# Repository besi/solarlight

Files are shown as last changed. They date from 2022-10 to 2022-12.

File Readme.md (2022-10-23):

# Solar Light
A smart, solar powered light that lights up in various colors.

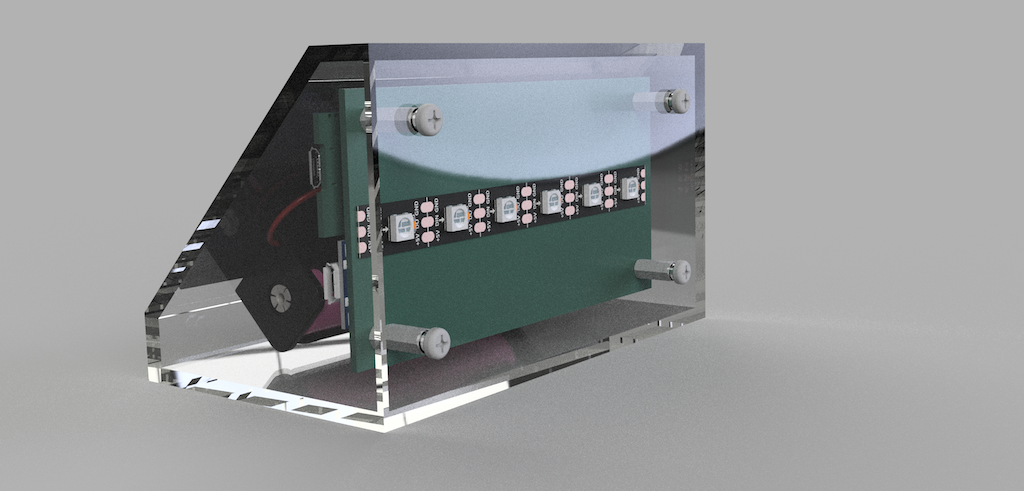
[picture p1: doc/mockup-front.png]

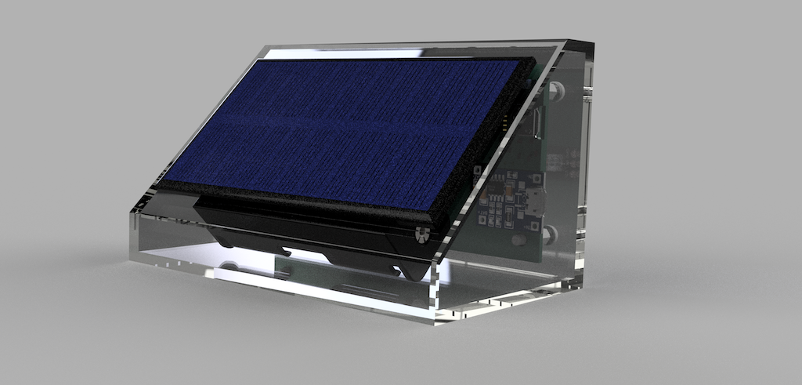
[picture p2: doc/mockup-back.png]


# Parts
The following parts are used in the project.

| Identifier  | Description | 
| --- | --- |
| [Microcontroller][]  | Wemos D1 Mini |
| [Battery][] | 18650 Lipo Battery with holder |
| [Charger][] | TP4056 Lipo Charger  |
| [Solar Panel][] | 110x60mm Solar Panel  |
| [Voltage Regulator][] | MCP1700-3302E  |
| [Neopixels][] | Neopixel WS2812b  |
| LED | Status LED  |
| Resistor | Resistor for LED Value? |
| Capacitor | Value? |

[Neopixels]: https://www.bastelgarage.ch/5m-ws2812b-60led-m-led-neopixel-strip-rolle
[Solar Panel]: https://www.bastelgarage.ch/solarzelle-5v-200ma-1w-110x60mm?search=solar%20panel
[Charger]: https://www.bastelgarage.ch/tp4056-lithium-lipo-akku-batterie-lademodul-micro-usb-5v-1a
[Battery]: https://www.bastelgarage.ch/li-ion-akku-3000ma-18650-mit-schutzelektronik-und-stecker?search=schutzelektronik
[Microcontroller]: https://www.reichelt.de/de/de/d1-mini-esp8266-v2-0-d1-mini-p253978.html?r=1
[Voltage Regulator]:https://www.digikey.ch/de/products/detail/microchip-technology/MCP1700-3302E-TO/652680

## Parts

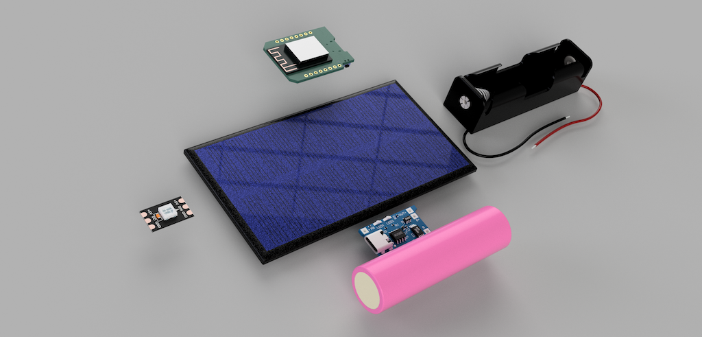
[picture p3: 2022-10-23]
doc/parts.png

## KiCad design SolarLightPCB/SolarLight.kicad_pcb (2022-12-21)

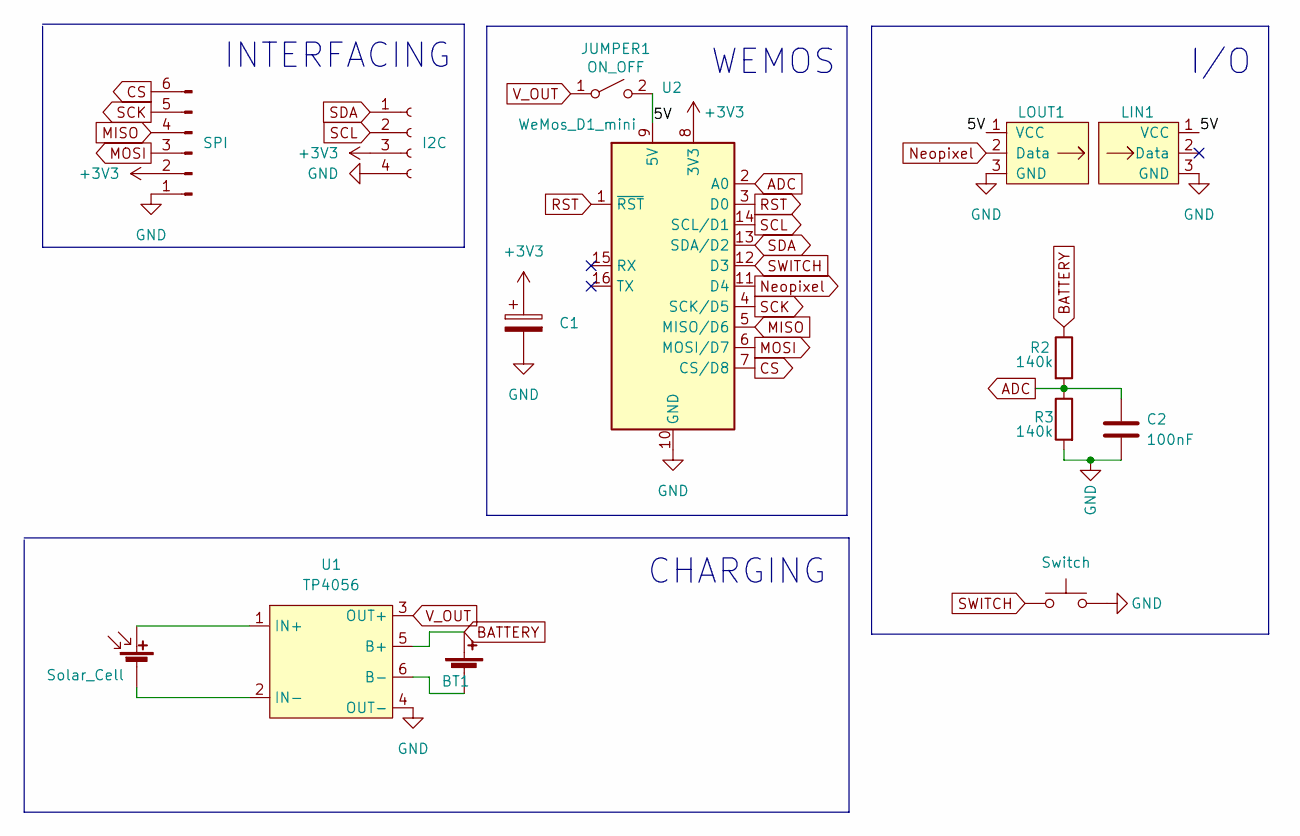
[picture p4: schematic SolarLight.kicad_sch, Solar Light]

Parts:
BT1: Battery_Cell; TerminalBlock_Phoenix_PT-1,5-2-3.5-H_1x02_P3.50mm_Horizontal
C1: C_Polarized; CP_Radial_D5.0mm_P2.50mm
C2: 100nF; C_Disc_D5.0mm_W2.5mm_P5.00mm
J1: I2C; PinHeader_1x04_P2.54mm_Vertical
J2: SPI; PinHeader_1x06_P2.54mm_Vertical
JUMPER1: ON_OFF; PinHeader_1x03_P2.54mm_Vertical
LIN1: LEDs_In; LED-Strip
LOUT1: LEDs_Out; LED-Strip
R2, R3: 140k; R_Axial_DIN0207_L6.3mm_D2.5mm_P7.62mm_Horizontal
SC1: Solar_Cell; TerminalBlock_Phoenix_PT-1,5-2-3.5-H_1x02_P3.50mm_Horizontal
SW1: Switch; SW_PUSH_6mm_H4.3mm
U1: TP4056
U2: WeMos_D1_mini; WEMOS_D1_mini_light

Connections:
+3V3: C1.1, J1.3, J2.2, U2.8 (3V3)
/5V: JUMPER1.2 (B), LIN1.1 (VCC), LOUT1.1 (VCC), U2.9 (5V)
ADC: C2.1, R2.2, R3.1, U2.2 (A0)
BATTERY: BT1.1 (+), R2.1, U1.5 (B+)
CS: J2.6, U2.7 (CS/D8)
GND: C1.2, C2.2, J1.4, J2.1, LIN1.3 (GND), LOUT1.3 (GND), R3.2, SW1.2, U1.4 (OUT-), U2.10 (GND)
MISO: J2.4, U2.5 (MISO/D6)
MOSI: J2.3, U2.6 (MOSI/D7)
Neopixel: LOUT1.2 (Data), U2.11 (D4)
unnamed: BT1.2 (-), U1.6 (B-)
unnamed: SC1.1 (+), U1.1 (IN+)
unnamed: SC1.2 (-), U1.2 (IN-)
RST: U2.1 (~RST), U2.3 (D0)
SCK: J2.5, U2.4 (SCK/D5)
SCL: J1.2, U2.14 (SCL/D1)
SDA: J1.1, U2.13 (SDA/D2)
SWITCH: SW1.1, U2.12 (D3)
V_OUT: JUMPER1.1 (A), U1.3 (OUT+)

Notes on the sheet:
INTERFACING
CHARGING
WEMOS
I/O

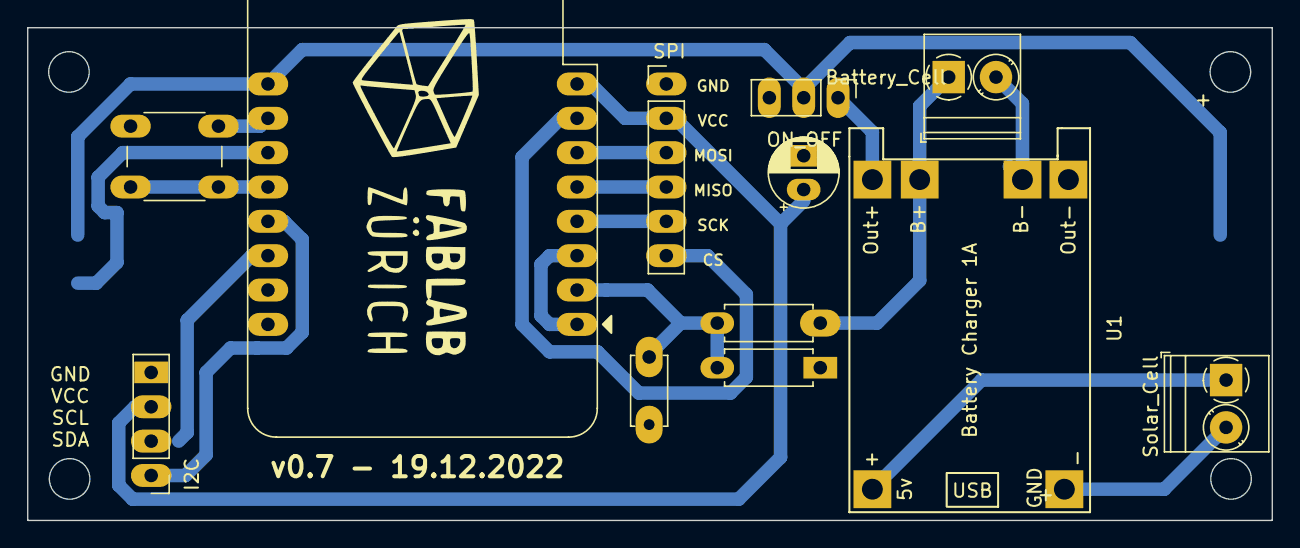
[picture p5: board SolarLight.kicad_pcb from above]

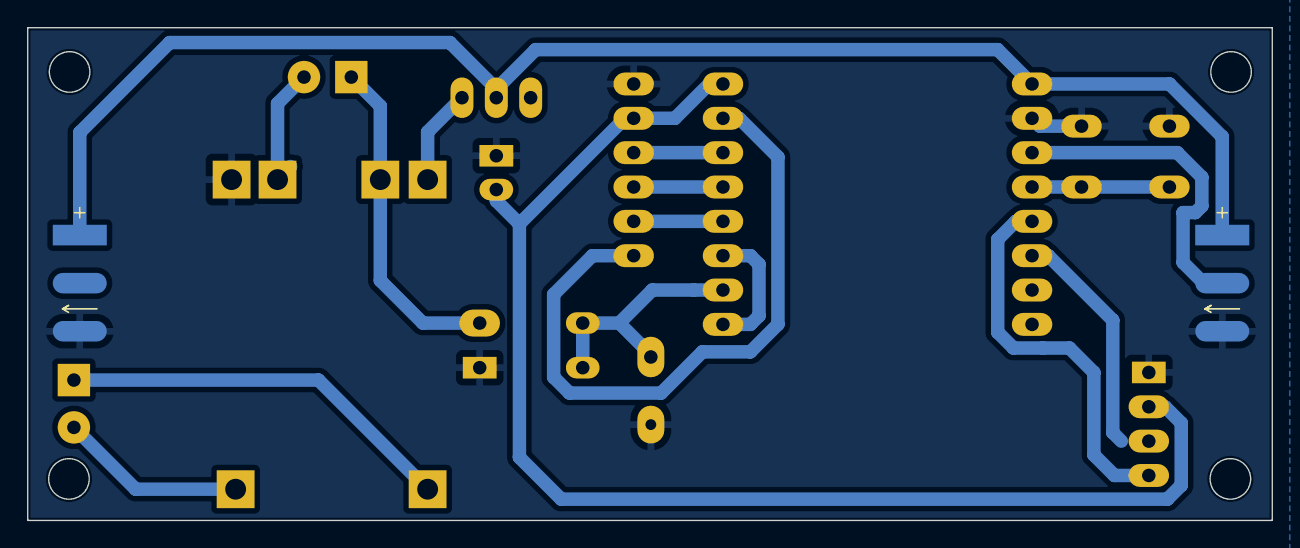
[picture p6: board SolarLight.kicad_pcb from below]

Board: 2 copper layers, 92.0 x 36.4 mm, 14 parts (2 on the bottom side), 18 nets.

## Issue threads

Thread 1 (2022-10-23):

Add parts list

besi, 2022-10-23:
Parts list

- [ ] 18650 Lipo
- [ ] 18650 Halterung
- [ ] TP4056
- [ ] Wemos D1 Mini
- [ ] Solar Panel
- [ ] MCP1700-3302E
- [ ] LED
- [ ] Capacitor
- [ ] Resistor
- [ ] 5 Neopixels

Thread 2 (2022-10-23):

MVP of the PCB

besi, 2022-10-23:
- [ ] Add Wemos Symbol & Footprint
- [ ] Add TP4056 Symbol & Footprnt
- [ ] Add Neopixel Symbol & Footprint
- [ ] MCP1700-3302E
- [ ] Wire it up

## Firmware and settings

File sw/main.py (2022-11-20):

import neopixel
import machine
import time

# ADC
from machine import ADC
adc = ADC(0)

# initialize I2C display
#from machine import Pin, I2C
#import ssd1306
#i2c = I2C(sda=Pin(4), scl=Pin(5))
#display = ssd1306.SSD1306_I2C(128, 60, i2c)

reset_pin = 16
reset = machine.Pin(reset_pin, machine.Pin.OUT)
reset.value(1)

mode = 0
mode_count = 6
mode_pin = 0
mode_button = machine.Pin(mode_pin, machine.Pin.IN, machine.Pin.PULL_UP)

neopixel_pin = 2
led_count = 5
np = neopixel.NeoPixel(machine.Pin(neopixel_pin), led_count)

def rainbow(led_count):
    # Rainbow code by https://wokwi.com/arduino/projects/305569065545499202

    rainbow = [
      (126 , 1 , 0),(114 , 13 , 0),(102 , 25 , 0),(90 , 37 , 0),(78 , 49 , 0),(66 , 61 , 0),(54 , 73 , 0),(42 , 85 , 0),
      (30 , 97 , 0),(18 , 109 , 0),(6 , 121 , 0),(0 , 122 , 5),(0 , 110 , 17),(0 , 98 , 29),(0 , 86 , 41),(0 , 74 , 53),
      (0 , 62 , 65),(0 , 50 , 77),(0 , 38 , 89),(0 , 26 , 101),(0 , 14 , 113),(0 , 2 , 125),(9 , 0 , 118),(21 , 0 , 106),
      (33 , 0 , 94),(45 , 0 , 82),(57 , 0 , 70),(69 , 0 , 58),(81 , 0 , 46),(93 , 0 , 34),(105 , 0 , 22),(117 , 0 , 10)]

    while True:
        rainbow = rainbow[-1:] + rainbow[:-1]
        for i in range(led_count):
            np[i] = rainbow[i]
            np.write()
        
        time.sleep_ms(100)

def read_battery():
    value = str(adc.read())
    print(value)
    #display.fill(0)
    #display.text('Voltage: ' + value, 0, 0, 1)
    #display.show()


def mode_changed(event):
    global mode, modes
    mode = mode + 1
    mode = mode % (mode_count + 1)
    print("new mode: " + str(mode))
    if mode == 1:
        read_battery()
    elif mode == 2:
        np.fill((255, 255, 255))
    elif mode == 3:
        np.fill((0, 0, 255))
    elif mode == 4:
        np.fill((255, 0, 0))
    elif mode == 5:
        np.fill((0, 255, 0))
    elif mode == 6:
        rainbow(led_count)
    np.write()
    time.sleep(1)

mode_button.irq(trigger=machine.Pin.IRQ_FALLING, handler=mode_changed)


def clear(): 
    np.fill((0, 0, 0))
    np.write()

def fivecolors():
    np[0] = (18,50,250)
    np[1] = (180,50,0)
    np[2] = (180,50,255)
    np[3] = (18,250,25)
    np[4] = (218,50,25)
    np.write()

fivecolors()
#rainbow(led_count)

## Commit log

2022-10-23 Add PCB
    [SolarLight.kicad_pcb, SolarLight.kicad_sch]
2022-10-23 Replace the missing connection with a jumper
    [SolarLight.kicad_pcb, SolarLight.kicad_sch]
2022-10-23 Add missing trace
    [SolarLight.kicad_pcb]
2022-10-23 Update schematic
    [SolarLight.kicad_sch]
2022-10-23 Add voltage divider to measure the battery voltage
    fixes #4
    [SolarLight.kicad_pcb, SolarLight.kicad_sch]
2022-10-23 Add a power on Jumper
    fixes #5
    [SolarLight.kicad_pcb, SolarLight.kicad_sch]
2022-10-23 Minor changes to PCB
    - Added _draft_ mounting holes
    - Added SPI and I2C labels
    - Changed the Board dimension to 100x45mm
    [SolarLight.kicad_pcb, SolarLight.kicad_sch]
2022-10-23 Update the pitch of the neopixel strips
2022-10-23 PCB Improvements
    - Bigger Package for the voltage regulator
    - Only one trace per pad (prefer to merge in the track instead)
    - Specify some minimal trace distance
    - Finer grid for the PCB to allow for better routing (5mils)
    - Cleanup unconnected traces
    - Ignore non-relevant DRC warnings
    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
    [SolarLight.kicad_pcb, SolarLight.kicad_sch]
2022-10-23 Add the output of the neopixel pin to GND
    For now not the 3.3V since it’s hard to route that one over there
    [SolarLight.kicad_pcb, SolarLight.kicad_sch]
2022-10-24 Fix wrong pin numbering on the 3.3 voltage regulator
    [SolarLight.kicad_pcb, SolarLight.kicad_sch]
2022-10-24 PCB Improvements
    - Remove the LED
    - Make the pads biggger
    - Add a GND Plane
    - Add a logo
    - Connect both GND and VCC pads of the mechanical neopixel pin
    - Align positive / negative pins of Battery and solar panel
    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
    [SolarLight.kicad_pcb, SolarLight.kicad_sch]
2022-10-24 Move the SPI header
    [SolarLight.kicad_pcb, SolarLight.kicad_sch]
2022-10-24 Cleanup some traces
    [SolarLight.kicad_pcb]
2022-10-25 Add rotary encoder
    [SolarLight.kicad_pcb, SolarLight.kicad_sch]
2022-11-03 Add GND Jumper
    [SolarLight.kicad_pcb, SolarLight.kicad_sch]
2022-11-09 Make a “simplified” version
    [SolarLight.kicad_pcb, SolarLight.kicad_sch]
2022-11-17 Updated the simple pcb
    [SolarLight.kicad_pcb, SolarLight.kicad_sch]
2022-11-17 Remove the voltage regulator
    [SolarLight.kicad_pcb, SolarLight.kicad_sch]
2022-11-17 Reduce board size
    [SolarLight.kicad_pcb]
2022-11-17 Add capacitor for measuring the Battery voltage
    [SolarLight.kicad_pcb]
2022-11-17 Remove unused pads
    [SolarLight.kicad_pcb]
2022-11-17 Add 1mm tracks
    [SolarLight.kicad_pcb]
2022-11-18 Move the I2C and ON-OFF jumper closer to the edge
    [SolarLight.kicad_pcb]
2022-11-18 Add the missing capacitor to the schema
    Fixing the warning because the pad of the charger module was removed
    [SolarLight.kicad_pcb, SolarLight.kicad_sch]
2022-11-18 Don’t commit rounded tracks
2022-11-20 Update silkscreen
    [SolarLight.kicad_pcb, SolarLight.kicad_sch]
2022-11-20 Added diode for reducing the voltage of the battery to ~3.3V
    [SolarLight.kicad_pcb, SolarLight.kicad_sch]
2022-12-19 Update TP4056 library
    [SolarLight.kicad_sch]
2022-12-19 Update schematics and bump to version 0.7
    [SolarLight.kicad_pcb, SolarLight.kicad_sch]
2022-12-19 Use the 5V to 3V3 regulator of the Wemos D1
    [SolarLight.kicad_pcb, SolarLight.kicad_sch]
2022-12-21 Remove the resistor for measuring the battery voltage even in the disconnected state
    [SolarLight.kicad_pcb, SolarLight.kicad_sch]
